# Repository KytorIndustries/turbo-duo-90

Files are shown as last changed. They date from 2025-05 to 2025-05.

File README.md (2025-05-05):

# Turbo Duo DIN 8 90 Degree
The PC Engine Duo / Turbo Duo DIN 8 AV port protrudes out the side, an inconvenience in some setups. This two piece PCB assembly is designed to rotate the DIN 8 connector 90 degrees to face towards the rear. The two pieces consist of the upper (3E-300011) and base (3E-300012).

The Turbo Duo uses a full-size DIN 5 connector, which if modded for RGB video one typically chooses a DIN 8 270 connector for consistency with the Duo R and readily available AV cables. Unfortunately PCB 180 mount DIN 8 270 male connectors are unavailable at this time, so this board is designed to accept both DIN 8 262 and 270 male connectors.

The only possibility at the time of this writing is to use DIN 8 262 male connectors which are technically incompatible with DIN 8 270 female, although if you bend the pins you can force it to work (functional, but not recommended). Therefore if using this device I would recommend replacing the PCB 90 mount DIN 8 270 female connector on your Turbo Tuo with a DIN 8 262 female connector.

The lower board includes an optional sync stripper for CSYNC output.

A provision is provided for mounting to a plastic enclosure shell. A shell has not been designed as part of this project.

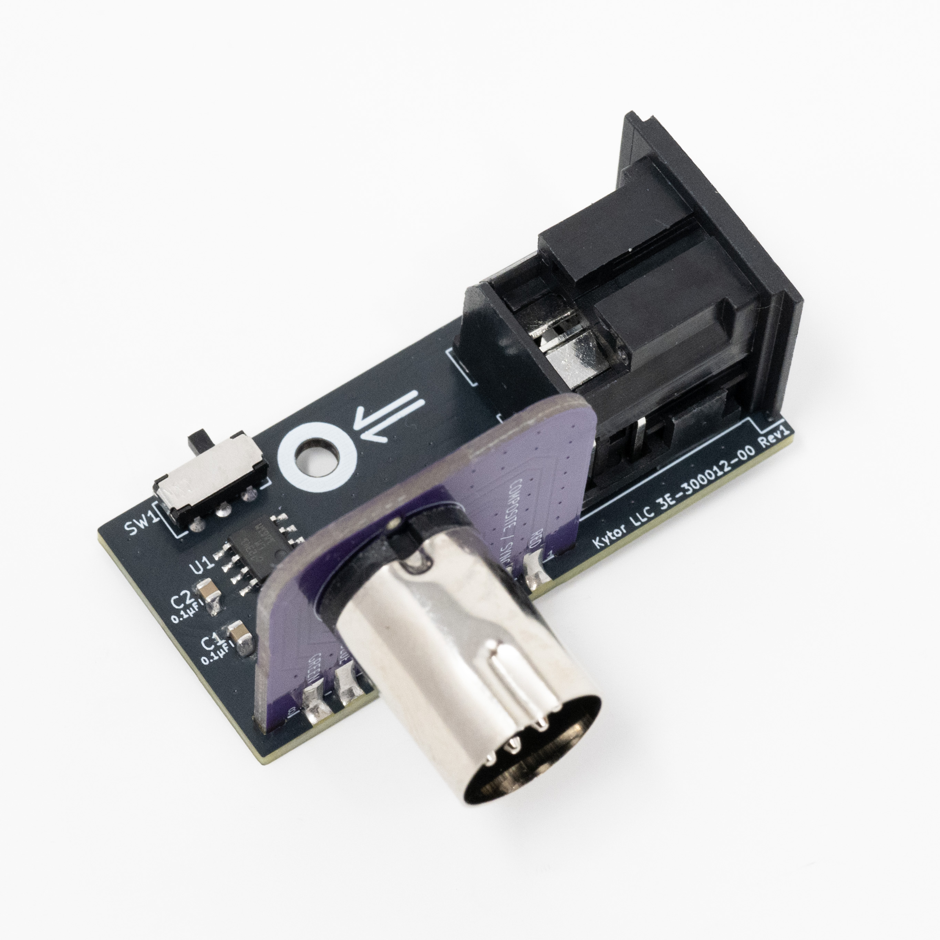
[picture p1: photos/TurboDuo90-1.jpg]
TurboDuo90


## Files Included
- **PCB Design Files** (KiCAD, Gerber)
- **Bill of Materials** (XLSX)
- **CAD** (STEP)
- **Photos**

## Assembly
1. Solder all components in place. Alternatively, if a sync stripper is not desired do not populate C1-2, SW1 or U1 and solder jumper JP1.
2. Solder upper board to lower board.

## PCB Revision History
- Rev 1 - Initial release
- Rev 0 - Development (unreleased)

## License
This project is open-source under the [CC BY 4.0 (Attribution 4.0 International)](https://creativecommons.org/licenses/by/4.0/).

## Disclaimer
This project is provided "as-is" without any warranty, express or implied, including but not limited to warranties of merchantability or fitness for a particular purpose. No support is provided.

Amazon links are affiliates.

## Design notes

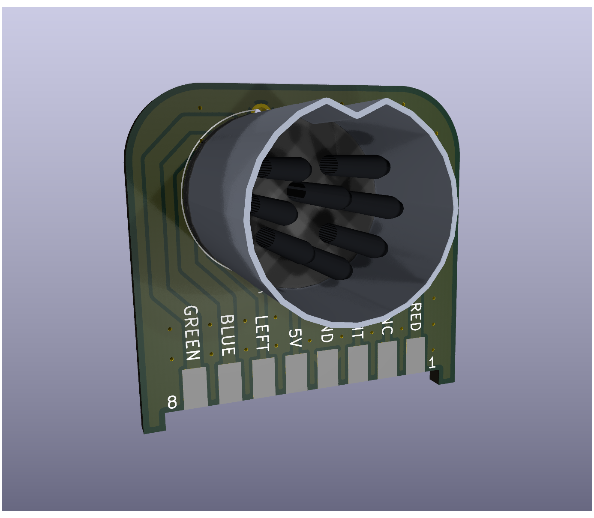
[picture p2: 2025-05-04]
photos/TurboDuo90.png

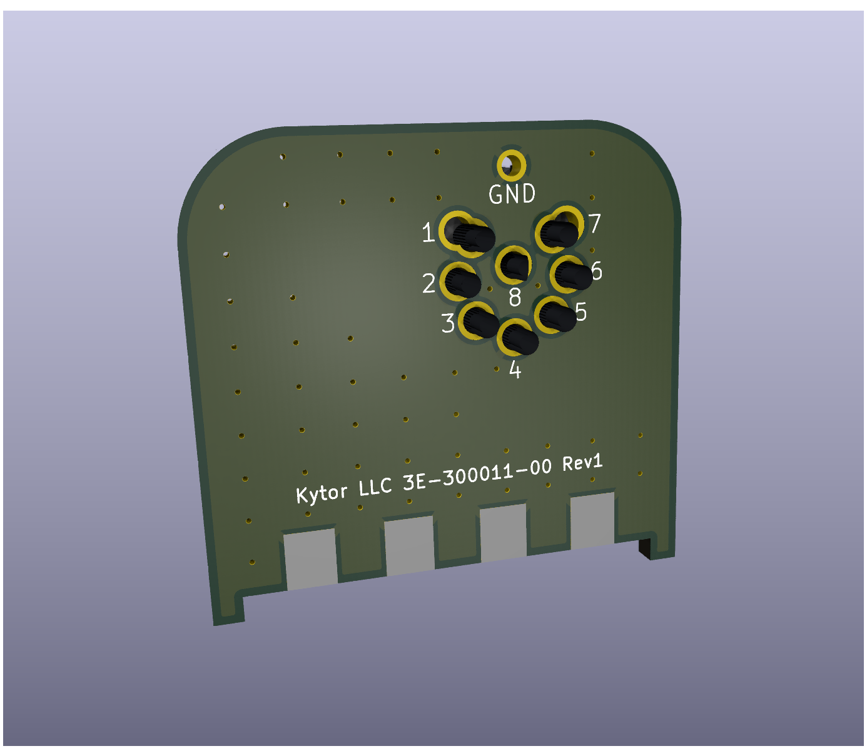
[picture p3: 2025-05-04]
photos/TurboDuo90-2.png

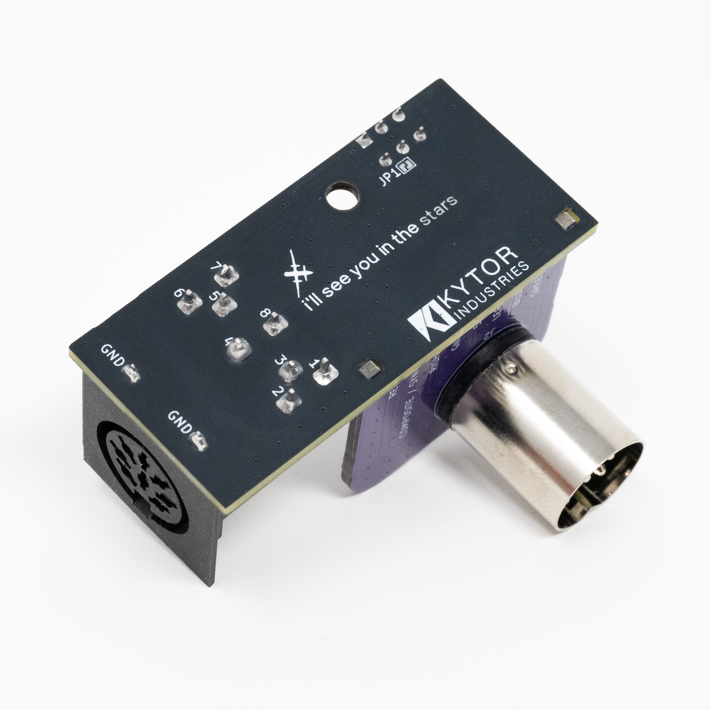
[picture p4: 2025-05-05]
photos/TurboDuo90-3.jpg

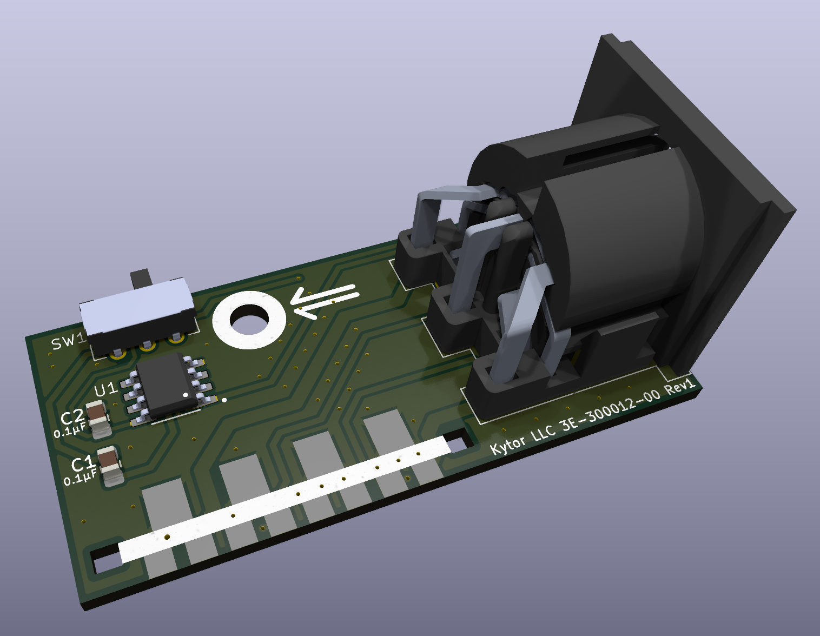
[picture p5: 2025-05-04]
photos/TurboDuoBase-Top.png

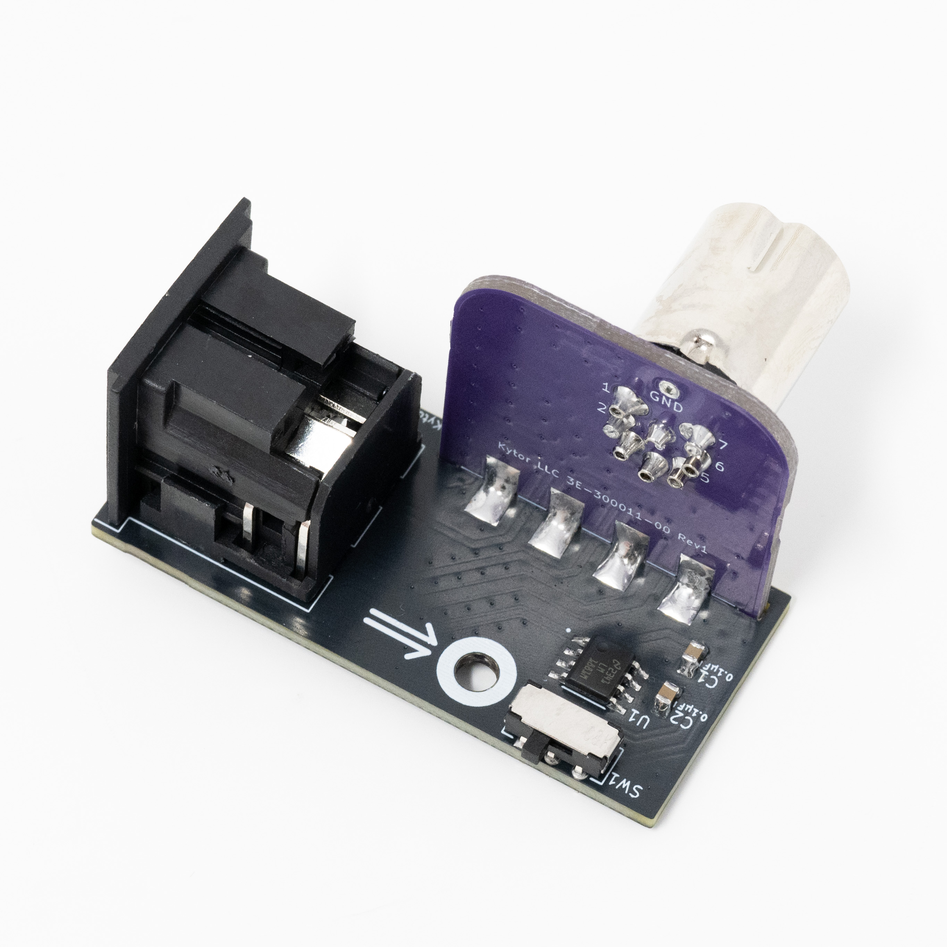
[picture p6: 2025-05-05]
photos/TurboDuo90-2.jpg

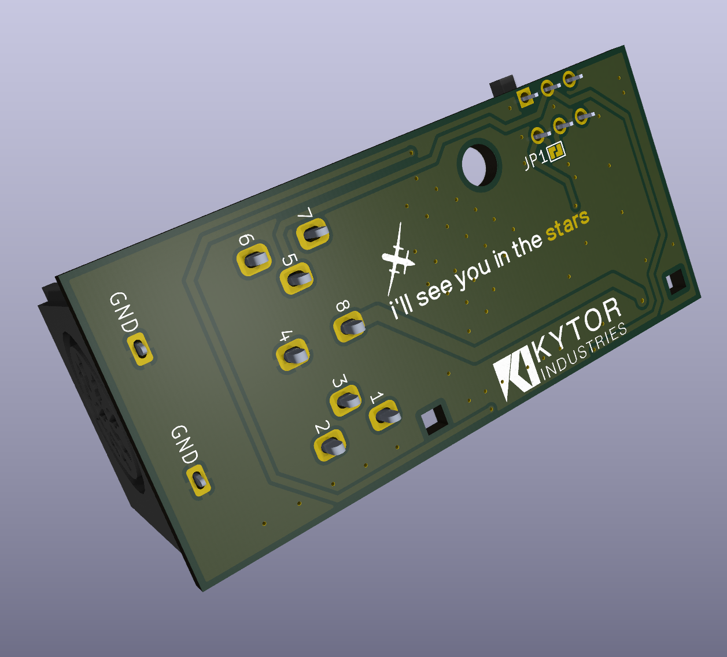
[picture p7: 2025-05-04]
photos/TurboDuoBase-Bottom.png

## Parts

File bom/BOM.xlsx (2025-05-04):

Name | Manufacturer | Quantity | Value | Pattern | RefDes | Procurement
Female 90 DIN 8 270 | RTLECS | 1 |  | DS-8-101-270 | J1 | https://www.aliexpress.us/item/3256802145433954.html
Male 180 DIN 8 262 | RTLECS | 1 |  | DIN 8 262 180 | J2 | https://www.aliexpress.us/item/3256801687296911.html
 | Various | 2 | 100nF | 805 | C1-2 | https://www.mouser.com/ProductDetail/Samsung-Electro-Mechanics/CL21B104KBFWPJE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
 | C&K | 1 |  | JS202011AQN | SW1 | https://www.mouser.com/ProductDetail/CK/JS202011AQN?qs=LgMIjt8LuD%252Bmsz6wAeWWtQ%3D%3D
 | Texas Instruments | 1 |  | SOIC-8 | U1 | https://www.mouser.com/ProductDetail/Texas-Instruments/LM1881M-NOPB?qs=X1J7HmVL2ZHgmlmivbQvCQ%3D%3D

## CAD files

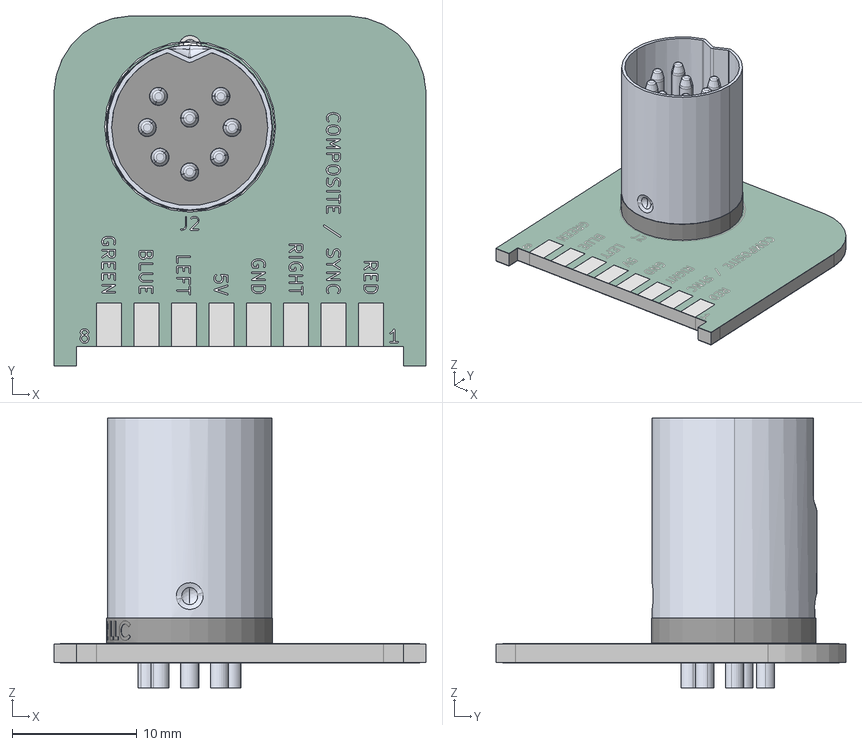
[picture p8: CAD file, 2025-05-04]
cad/3E-300011_TurboDuo-DIN-8-Upper.step
29.8 x 28.0 x 21.6 mm
Barrel
Insert
Pin x 7
Pin - Center
TurboDuo90_copper
TurboDuo90_pad
TurboDuo90_via
TurboDuo90_silkscreen
TurboDuo90_soldermask
TurboDuo90_PCB

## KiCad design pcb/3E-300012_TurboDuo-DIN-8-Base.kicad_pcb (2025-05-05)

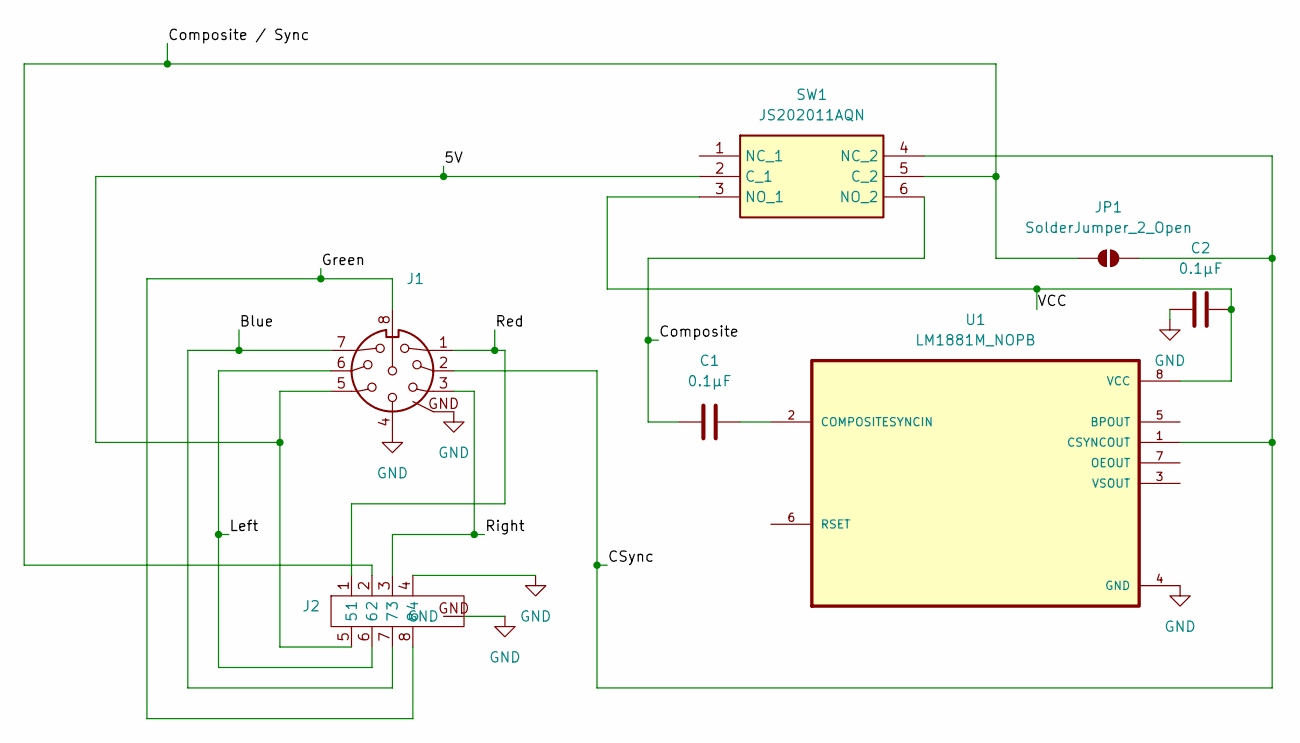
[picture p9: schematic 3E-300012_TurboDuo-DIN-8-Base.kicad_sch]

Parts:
C1, C2: 0.1µF; C_0805_2012Metric_Pad1.18x1.45mm_HandSolder
J1: DIN_8_270_Female_(90)
J2: Tee Joint 9 Pin Plane
JP1: SolderJumper_2_Open; Jumper Small (1.5x1mm)
SW1: JS202011AQN; Mouser Part Number 611-JS202011AQN
U1: LM1881M_NOPB; LM1881M

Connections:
/5V: J1.5, J2.5, SW1.2 (C_1)
/Blue: J1.7, J2.7
/CSync: J1.2, JP1.2 (B), SW1.4 (NC_2), U1.1 (CSYNCOUT)
/Composite: C1.1, SW1.6 (NO_2)
/Composite / Sync: J2.2, JP1.1 (A), SW1.5 (C_2)
/Green: J1.8, J2.8
/Left: J1.6, J2.6
/Red: J1.1, J2.1
/Right: J1.3, J2.3
/VCC: C2.2, SW1.3 (NO_1), U1.8 (VCC)
GND: C2.1, J1.4, J1.GND, J2.4, J2.GND, U1.4 (GND)
unnamed: C1.2, U1.2 (COMPOSITESYNCIN)

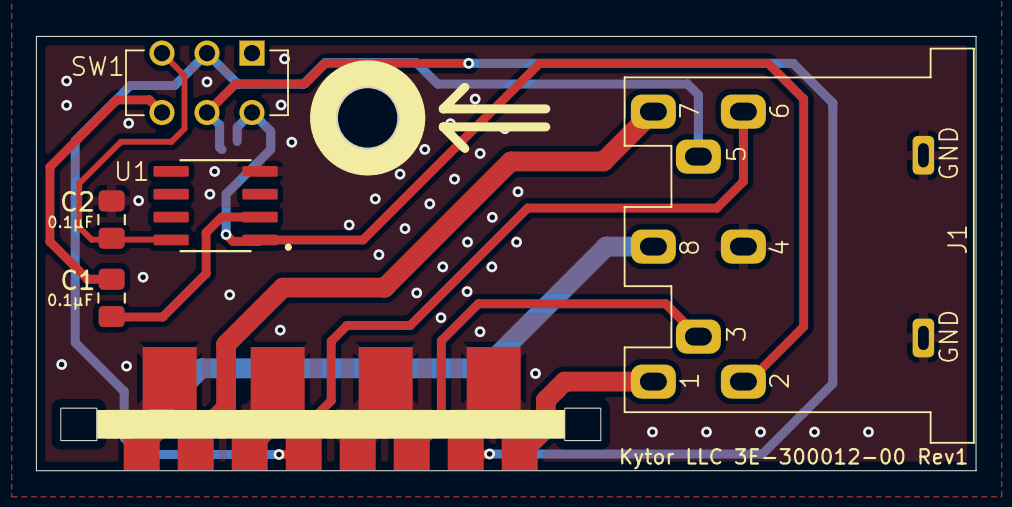
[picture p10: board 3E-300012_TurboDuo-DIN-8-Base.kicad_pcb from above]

Board: 2 copper layers, 52.2 x 24.1 mm, 7 parts (1 on the bottom side), 12 nets.

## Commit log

2025-05-04 Initial Upload
    [3E-300011_TurboDuo-DIN-8-Upper.kicad_pcb, 3E-300011_TurboDuo-DIN-8-Upper.kicad_sch, 3E-300011_TurboDuo-DIN-8-Upper.step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]
2025-05-05 Embedded Models
    KiCAD PCB Layout files now include embedded STEP files for components.
    [3E-300011_TurboDuo-DIN-8-Upper.kicad_pcb, 3E-300012_TurboDuo-DIN-8-Base.kicad_pcb]
